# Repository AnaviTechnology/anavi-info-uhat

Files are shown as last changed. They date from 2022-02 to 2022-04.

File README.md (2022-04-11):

# ANAVI Info uHAT

ANAVI Info uHAT is an open source hardware Raspberry Pi uHAT (add-on board) for rapid prototyping of Internet of Things (IoT) powered by free and open source software. It features:

* 3 Buttons
* Red and green indication LEDs
* Slot of mini OLED I2C display
* Slots for up to 3 plug and play I2C sensors for temperature, barometric pressure, humidity and light
* UART (Universal asynchronous receiver/transmitter) pins for debugging

# Safety Information

## English

### Warnings

* This product shall only be connected to a compatible Raspberry Pi.

### Instructions for safe use

* Do not expose this product to water or moisture, and do not place it on a conductive surface whilst in operation.
* Do not expose this product to heat from any source; it is designed for reliable operation at normal room temperatures.
* Take care while handling this product to avoid mechanical or electrical damage to the printed circuit board and connectors.
* Avoid handling this product while it is powered. Only handle by the edges to minimize the risk of electrostatic discharge damage.

## Deutsch

### Achtung

* Dieses Produkt darf nur mit einem kompatiblen Raspberry Pi verbunden werden.

### Anweisungen für die sichere Verwendung

* Setzen Sie dieses Produkt nicht Wasser oder Feuchtigkeit aus und stellen Sie es während des Betriebs nicht auf eine leitfähige Oberfläche.
* Setzen Sie dieses Produkt keiner Wärmequelle aus. Es ist für einen zuverlässigen Betrieb bei normalen Raumtemperaturen ausgelegt.
* Seien Sie vorsichtig beim Umgang mit diesem Produkt, um mechanische oder elektrische Schäden an der Leiterplatte und den Anschlüssen zu vermeiden.
* Vermeiden Sie die Handhabung dieses Produkts während der Stromversorgung. Produkt nur an den Rändern anfassen, um das Risiko von elektrostatischen Entladungsschäden zu minimieren.

# License

The project is released under the [Creative Commons Attribution-ShareAlike 4.0 International (CC BY-SA 4.0)](https://creativecommons.org/licenses/by-sa/4.0/).

Note: This is a human-readable summary of (and not a substitute for) the [license](https://creativecommons.org/licenses/by-sa/4.0/legalcode).

You are free to:

Share — copy and redistribute the material in any medium or format Adapt — remix, transform, and build upon the material for any purpose, even commercially. The licensor cannot revoke these freedoms as long as you follow the license terms. Under the following terms:

Attribution — You must give appropriate credit, provide a link to the license, and indicate if changes were made. You may do so in any reasonable manner, but not in any way that suggests the licensor endorses you or your use. ShareAlike — If you remix, transform, or build upon the material, you must distribute your contributions under the same license as the original. No additional restrictions — You may not apply legal terms or technological measures that legally restrict others from doing anything the license permits. Notices:

You do not have to comply with the license for elements of the material in the public domain or where your use is permitted by an applicable exception or limitation. No warranties are given. The license may not give you all of the permissions necessary for your intended use. For example, other rights such as publicity, privacy, or moral rights may limit how you use the material.

You will have to provide a link to the original creator of the project http://www.anavi.technology on any documentation or website.

Credit can be attributed through a link to the creator website: http://www.anavi.technology

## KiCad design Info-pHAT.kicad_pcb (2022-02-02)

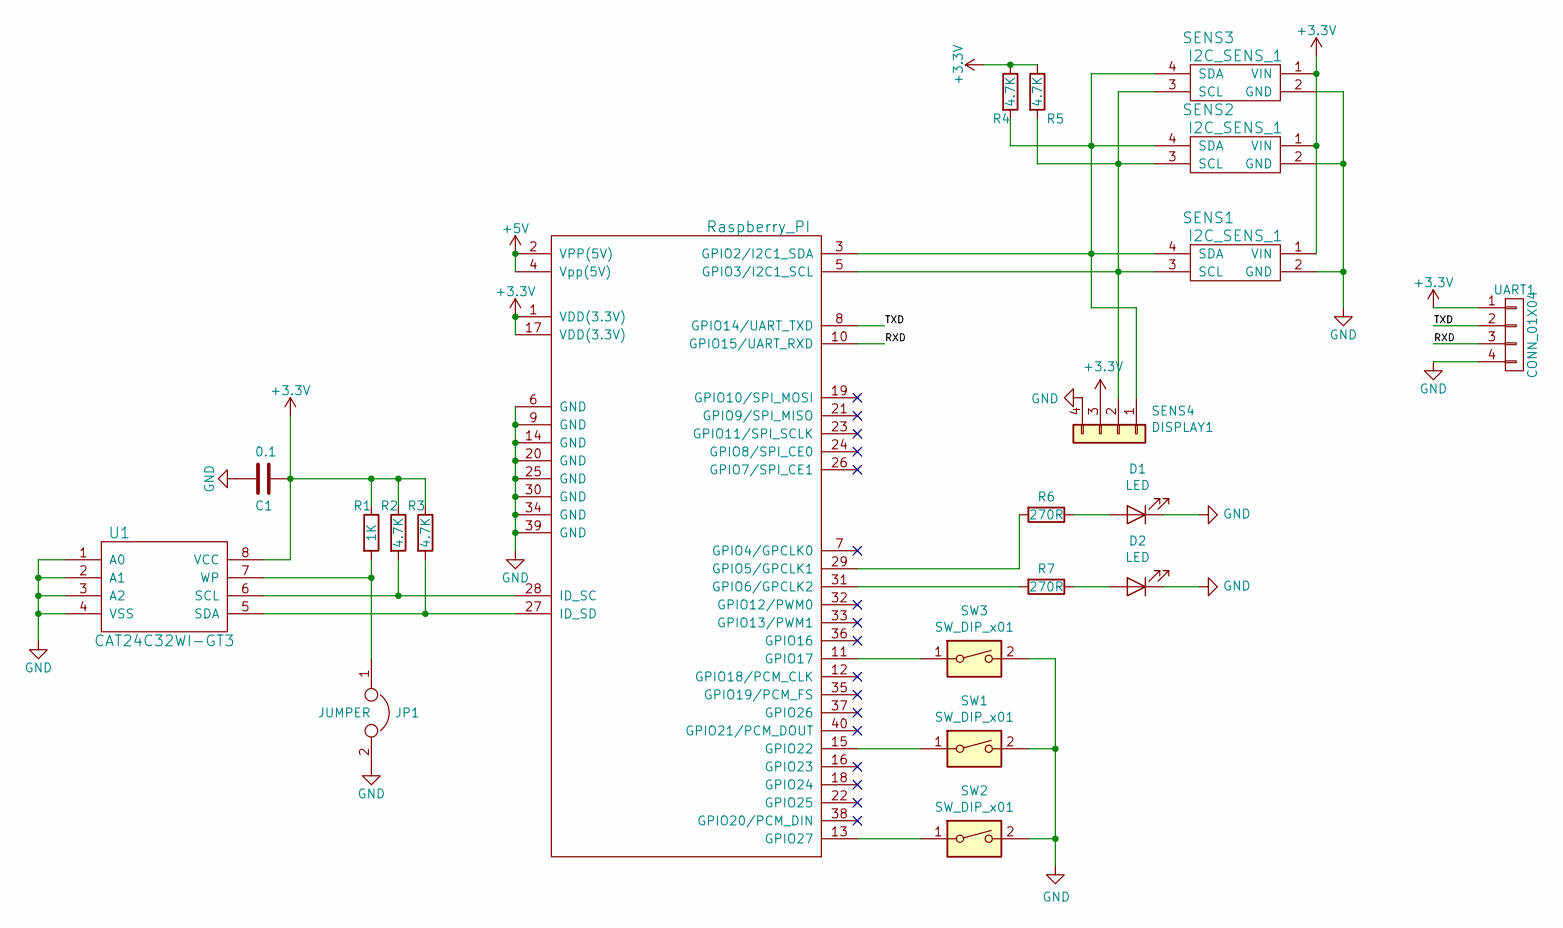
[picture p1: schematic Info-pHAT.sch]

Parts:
C1: 0.1; C_0603_HandSoldering
D1, D2: LED; LED_1206_3216Metric
JP1: JUMPER; Pin_Header_Straight_1x02
R1: 1K; R_0603_HandSoldering
R2, R3, R4, R5: 4.7K; R_0603_HandSoldering
R6, R7: 270R; R_0603_HandSoldering
RASP_CONN1: Raspberry_PI; Pin_Header_Straight_2x20
SENS1, SENS2, SENS3: I2C_SENS_1; Pin_Header_Straight_1x04
SENS4: DISPLAY1; Pin_Header_Straight_1x04
SW1, SW2, SW3: SW_DIP_x01; SW_PUSH_6mm_h4.3mm
U1: CAT24C32WI-GT3; DIP-8_W7.62mm
UART1: CONN_01X04; Pin_Header_Straight_1x04

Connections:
+3V3: C1.1, R1.1, R2.1, R3.1, R4.1, R5.1, RASP_CONN1.1 (VDD(3.3V)), RASP_CONN1.17 (VDD(3.3V)), SENS1.1 (VIN), SENS2.1 (VIN), SENS3.1 (VIN), SENS4.3, U1.8 (VCC), UART1.1; also elsewhere on the board
+5V: RASP_CONN1.2 (VPP(5V)), RASP_CONN1.4 (Vpp(5V))
/RXD: RASP_CONN1.10 (GPIO15/UART_RXD), UART1.3; also elsewhere on the board
/TXD: RASP_CONN1.8 (GPIO14/UART_TXD), UART1.2; also elsewhere on the board
GND: C1.2, D1.1 (K), D2.1 (K), JP1.2, RASP_CONN1.6 (GND), RASP_CONN1.9 (GND), RASP_CONN1.14 (GND), RASP_CONN1.20 (GND), RASP_CONN1.25 (GND), RASP_CONN1.30 (GND), RASP_CONN1.34 (GND), RASP_CONN1.39 (GND), SENS1.2 (GND), SENS2.2 (GND), SENS3.2 (GND), SENS4.4, SW1.2, SW2.2, SW3.2, U1.1 (A0), U1.2 (A1), U1.3 (A2), U1.4 (VSS), UART1.4; also elsewhere on the board
unnamed: D1.2 (A), R6.1
unnamed: D2.2 (A), R7.1
unnamed: JP1.1, R1.2, U1.7 (WP)
unnamed: R2.2, RASP_CONN1.28 (ID_SC), U1.6 (SCL)
unnamed: R3.2, RASP_CONN1.27 (ID_SD), U1.5 (SDA)
unnamed 10: R4.2, RASP_CONN1.3 (GPIO2/I2C1_SDA), SENS1.4 (SDA), SENS2.4 (SDA), SENS3.4 (SDA), SENS4.1; also elsewhere on the board
unnamed 11: R5.2, RASP_CONN1.5 (GPIO3/I2C1_SCL), SENS1.3 (SCL), SENS2.3 (SCL), SENS3.3 (SCL), SENS4.2; also elsewhere on the board
unnamed: R6.2, RASP_CONN1.29 (GPIO5/GPCLK1)
unnamed: R7.2, RASP_CONN1.31 (GPIO6/GPCLK2)
unnamed: RASP_CONN1.11 (GPIO17), SW3.1
unnamed: RASP_CONN1.13 (GPIO27), SW2.1
unnamed: RASP_CONN1.15 (GPIO22), SW1.1

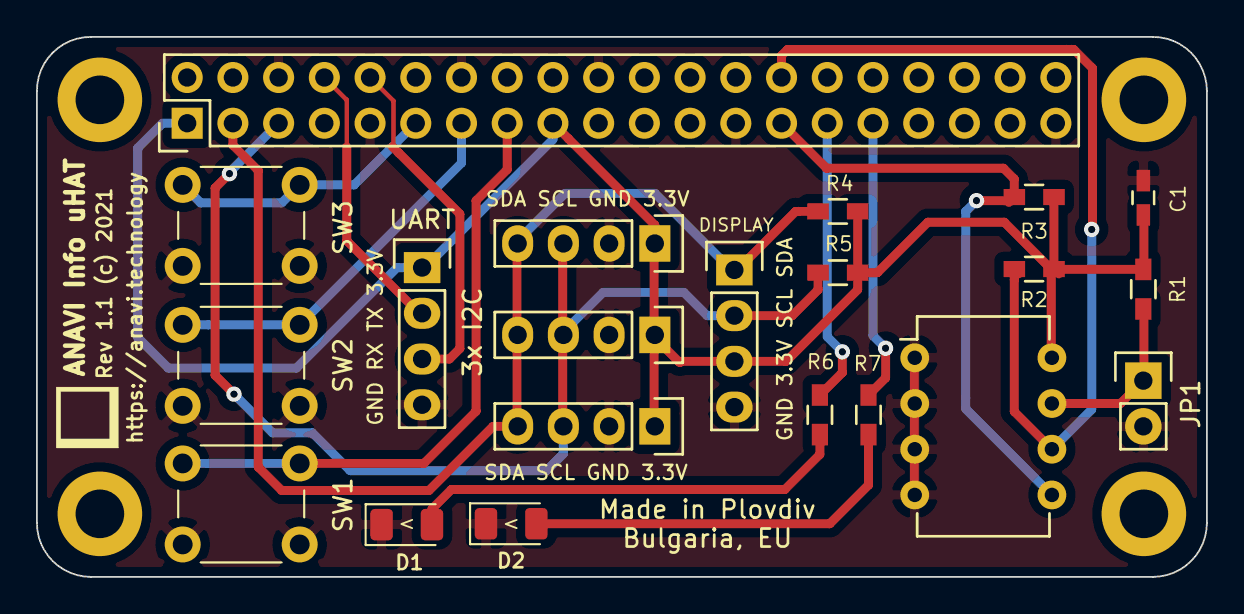
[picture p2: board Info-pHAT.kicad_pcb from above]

Board: 2 copper layers, 65.0 x 30.0 mm, 25 parts (0 on the bottom side), 17 nets.

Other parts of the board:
DISPLAY: DISPLAY1; Pin_Header_Straight_1x04
REF1, REF2, REF3, REF4: MountingHole_2.7mm_M2.5_DIN965_Pad
UART: CONN_01X04; Pin_Header_Straight_1x04

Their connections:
+3V3: DISPLAY.3, UART.1; also elsewhere on the board
/RXD: UART.3; also elsewhere on the board
/TXD: UART.2; also elsewhere on the board
GND: DISPLAY.4, UART.4; also elsewhere on the board
unnamed 10: DISPLAY.1; also elsewhere on the board
unnamed 11: DISPLAY.2; also elsewhere on the board

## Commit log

2021-06-22 Info-pHAT.pro: Add LED D1 and D2
    Add indication LEDs D1 and D2.
    [Info-pHAT.kicad_pcb, Info-pHAT.sch]
2021-06-23 Info-pHAT.kicad_pcb: Update labels
    Update labels and adjust positions.
    [Info-pHAT.kicad_pcb]
2021-07-05 Info-pHAT.kicad_pcb: Add a label
    Add a label for the direction of the LEDs.
    [Info-pHAT.kicad_pcb]
2021-12-30 README.md: Rename for pHAT to uHAT
    Rename the project from ANAVI Info pHAT to ANAVI Info uHAT
    because it covers all Raspberry Pi requirements for uHAT, a.k.a.
    micro Hardware Attached on Top.
2022-02-02 Info-pHAT.kicad_pcb: Add assembly details
    Add details for the assembly to the fabrication layer.
    [Info-pHAT.kicad_pcb]

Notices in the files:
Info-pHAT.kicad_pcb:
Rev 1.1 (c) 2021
